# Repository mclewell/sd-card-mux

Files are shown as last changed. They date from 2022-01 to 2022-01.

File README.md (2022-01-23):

# SD-Card-Mux
A tool to automate testing SD-Card images on embedded devices.

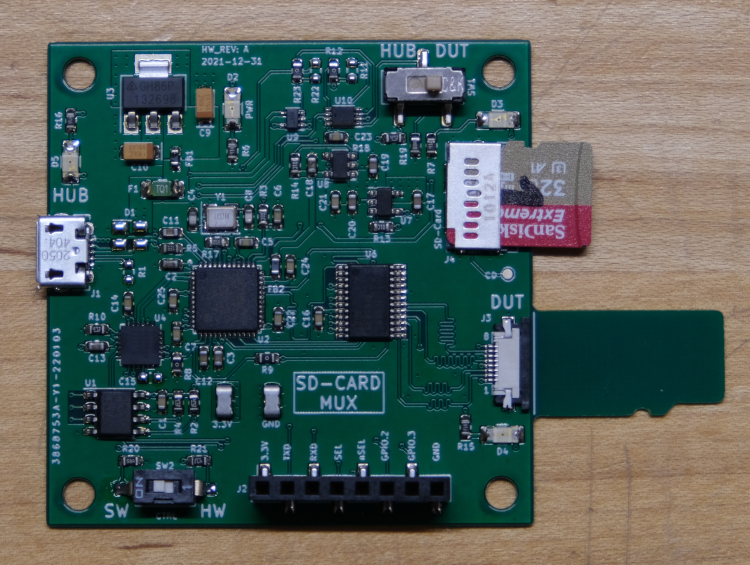
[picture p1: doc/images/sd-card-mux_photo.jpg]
SD-Card-Mux Phot


When developing images for embedded devices, do you often find yourself 
constanly moving the SD-Card between the embedded device and development
computer? Surely there is a way to automate this switching...

The SD-Card Mux sits between the host development computer and an
embedded device, such as a Beaglebone Black, and allows an SD-Card to be 
programatically switched between the two.

SD-Card Mux Block Diagram

The board uses a USB hub (U2640) that contains an SD-Card/MMC interface. A
standard micro-SD Card connects to this interface. One of the other USB ports 
on the hub connects to a USB-UART bridge (CP2102N). This bridge prodives a UART 
interface to the DUT and also controls the switching on the mux (TS3A27518E) 
using the GPIO on the bridge. The GPIO is controlled by the host computer 
using ```libgpiod```. 

Normally, the SD-Card is connected to the host computer. An image that is to be
booted by the DUT is written to the SD-Card. Instead of manually removing the 
card and inserting it into the DUT, a simple script can be added to the 
software development tooling to switch the card from the host computer to the 
embedded DUT.

## Usage
The SD-Card-Mux switching can be either controlled via software or manually
using the switch (```SW1```) on the top of the board.

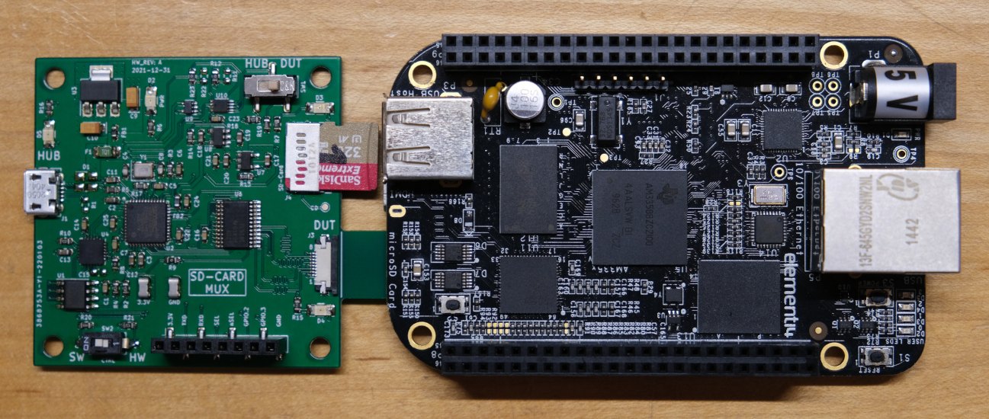
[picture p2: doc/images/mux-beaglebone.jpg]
Mux with Beaglebone Black


### Software Control
Prerequisite: ```libgpiod```

Ubuntu:
```
sudo apt install libgpiod libgpiod-dev
```

Arch: Install from the AUR: 
```
https://aur.archlinux.org/packages/libgpiod/
```

1. Set SW2 (bottom left corner) to 'HW'. (**Note:** Silkscreen labels
on the board are backwards)
2. Insert a micro-sd card into J4.
3. Insert the sd-card-mux into the micro-sd card slot of the development board.
4. Connect a micro-USB cable between the sd-card-mux and development PC.
5. On power-up the sd-card-mux will route the SD card to the DUT, as denoted by the
illuminated LED by the micro-sd protrusion.
6. To switch the SD card to the development PC:
	
	6a. Find the GPIO controller name of the CP210N:
	```
	$ sudo gpiodetect
	gpiochip0 [INT34BB:00] (312 lines)
	gpiochip1 [cp210x] (4 lines)
	```
	6b. The mux control line is on ```GPIO.0```. To switch,
	```
	$ sudo gpioset gpiochip1 0=0
	```
	The LED next to the micro-sd card slot will blink when the SD-Card is
	accessed.

#### UART and Additional GPIO
The SD-Card-Mux also contains a USB-UART serial bridge. Conect the ```TXD```
and ```RXD``` signals in J2 to the UART on the DUT. The bridge should appear
on the development computer as ```/dev/ttyUSB0```.

There are also two additional GPIO from the CP210N broken out into the J2 
header (```GPIO.2```, ```GPIO.3```). These signals can be controlled in the same
fashion as the mux switch function using ```gpioset```. One of these lines can
be connected to the reset of the DUT. Ideally, the DUT should be held in reset
while the SD-card is switched. Once switched over, the reset line can be released
allowing the DUT to boot the new image. 

### Manual Control
1. Set SW2 to the 'SW' position. (**Note:** Silkscreen labels on the board are
backwards)
2. Use SW1 to switch the micro-SD card between the DUT and development 
computer. (**Note:** the silkscreen labels are also backwards here).

# Acknowledgements
- https://wiki.tizen.org/SDWire
- https://github.com/kopasiak/sd-mux

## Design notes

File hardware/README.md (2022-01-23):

# Development Features
Since this was the first hardware spin of the board, some
development features were included.

## Software Switching
The software switching controlled through the CP210N GPIO control
the enable lines of two high-side power switches (```U7```/```U8```).
Only one of these switches should be enabled at a time, therefore the 
complementary output of ```U10``` is used. I had concerns that there
wouldn't be enough 'downtime' during the switch event to allow the 
on-board micro-sd card to fully powerdown before switching. 

The ```U10``` mux can be bypassed by using a GPIO.1 on the CP201N as 
the complementary switching singal. 
- Remove ```R12``` and ```R23```
- Install ```R11``` and ```R22```

During my testing, I have not seen any issues using the single mux
switch control line and mux complementary out.

## DUT Connection via FFC
A Flex-Flex Cable (FFC) header (```J3```) is provided to allow connections
to the DUT via a flex cable. The other end of the cable is connected to a
micro-sd breakout board, which is provided in this repo 
[here](microsd-breakout).

# Known Issues
- Silkscreen labels on ```S1``` and ```SW2``` are reversed.
- On-board micro-sd card in ```J4``` protrudes over the board edge
and may interfer with the DUT.
- The USB ESD protection (```D1```) caused the USB hub to fail to enumerate
at high-speed modes, full-speed works correctly. Removing ```D1``` solves
this issue.

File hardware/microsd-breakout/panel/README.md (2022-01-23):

The micro-sd breakout board can be panelized using 
[kikit](https://github.com/yaqwsx/KiKit). The panel parameters
are defined in ```panelize.json``` 

Run ```mk-panel.sh``` to generate a 2x5 panel of micro-sd breakout
board.

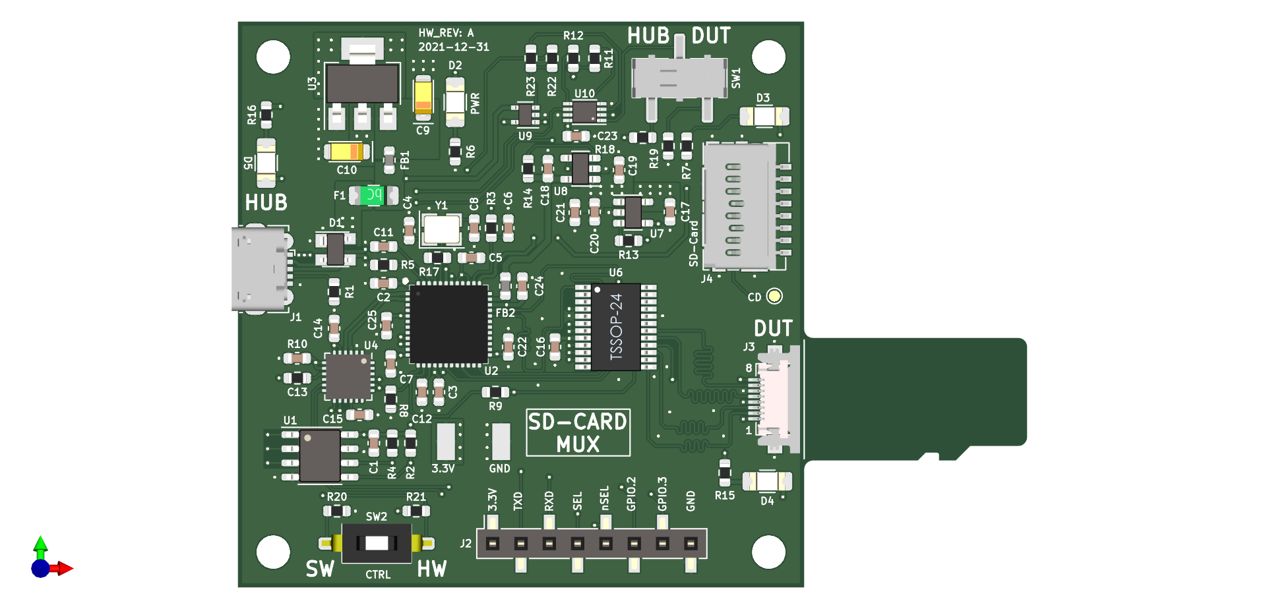
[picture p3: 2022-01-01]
doc/images/sd-card-mux.png

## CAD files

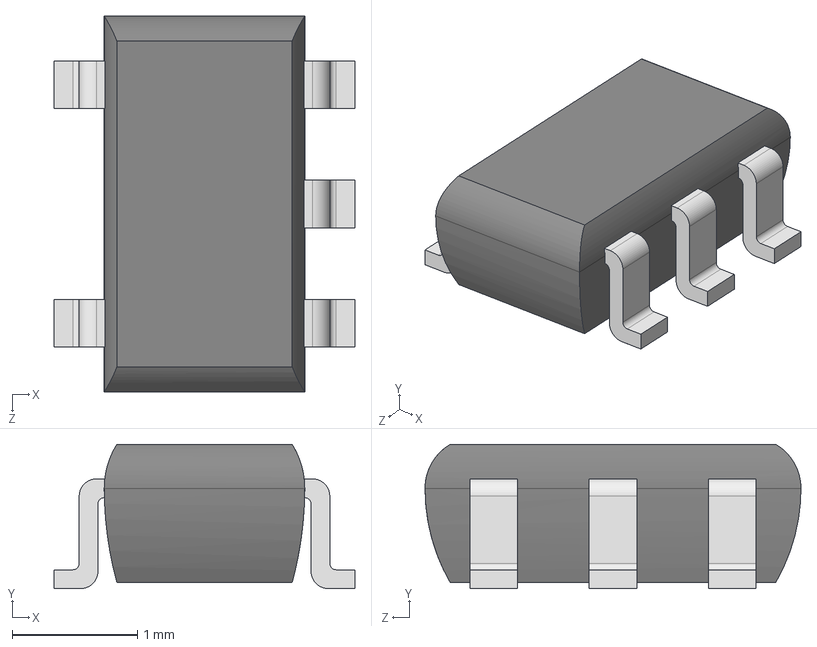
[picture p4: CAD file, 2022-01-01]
hardware/main/models/sot25.step
2.40 x 1.15 x 3.00 mm

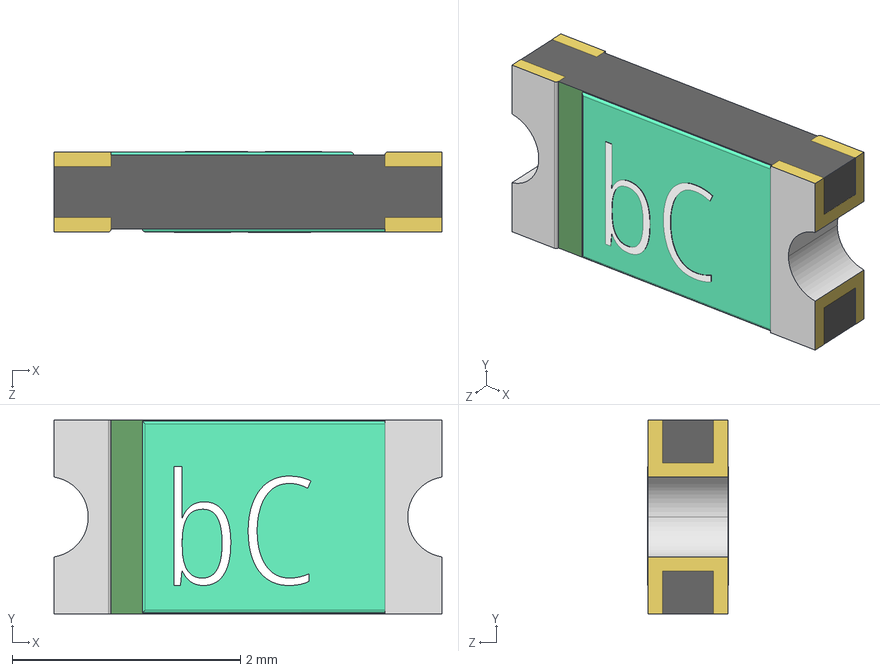
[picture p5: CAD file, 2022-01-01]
hardware/main/models/0ZCJ0005FF2E.step
3.40 x 1.70 x 0.708 mm

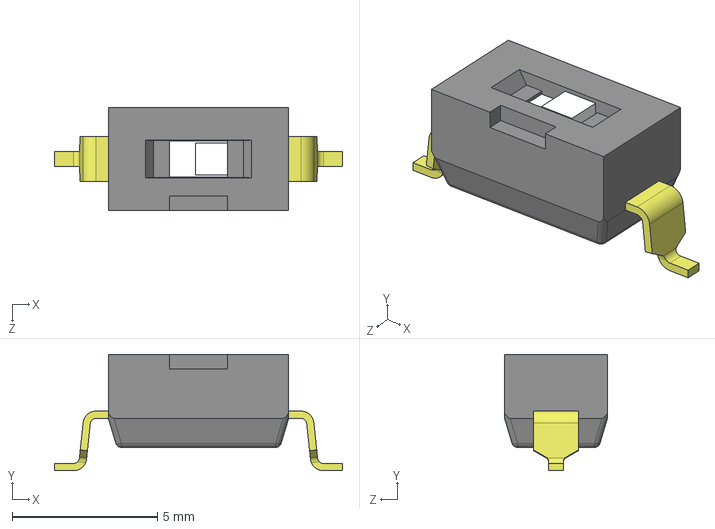
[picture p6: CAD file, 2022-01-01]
hardware/main/models/CUI_DEVICES_DS04-254-2-01BK-SMT.step
9.90 x 4.00 x 3.54 mm

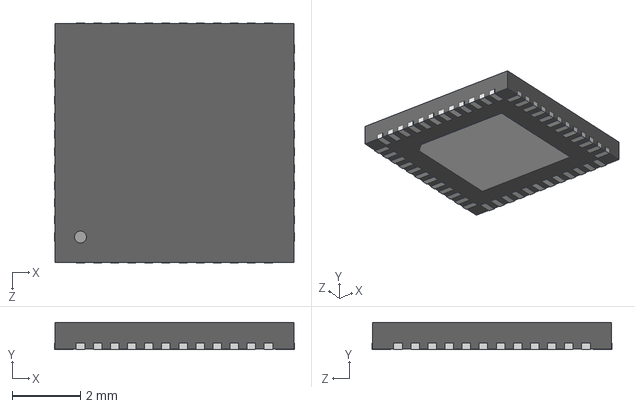
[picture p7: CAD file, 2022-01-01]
hardware/main/models/QFN48_7x7.step
7.02 x 0.8 x 7.02 mm

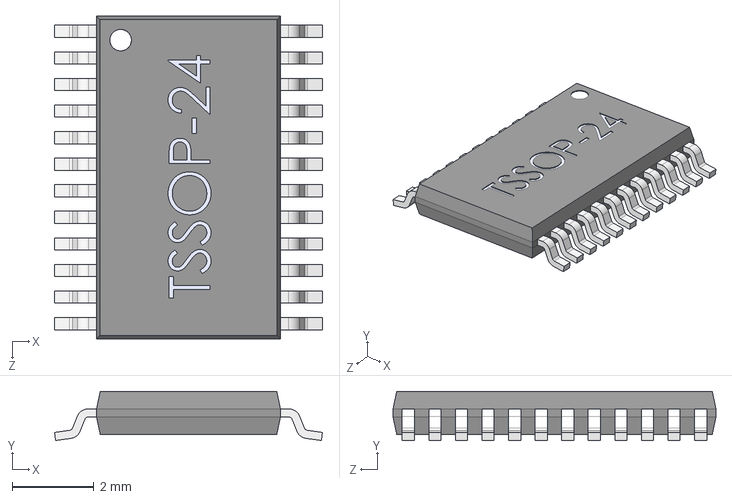
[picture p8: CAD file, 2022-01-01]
hardware/main/models/TSSOP24.step
6.56 x 1.20 x 7.90 mm

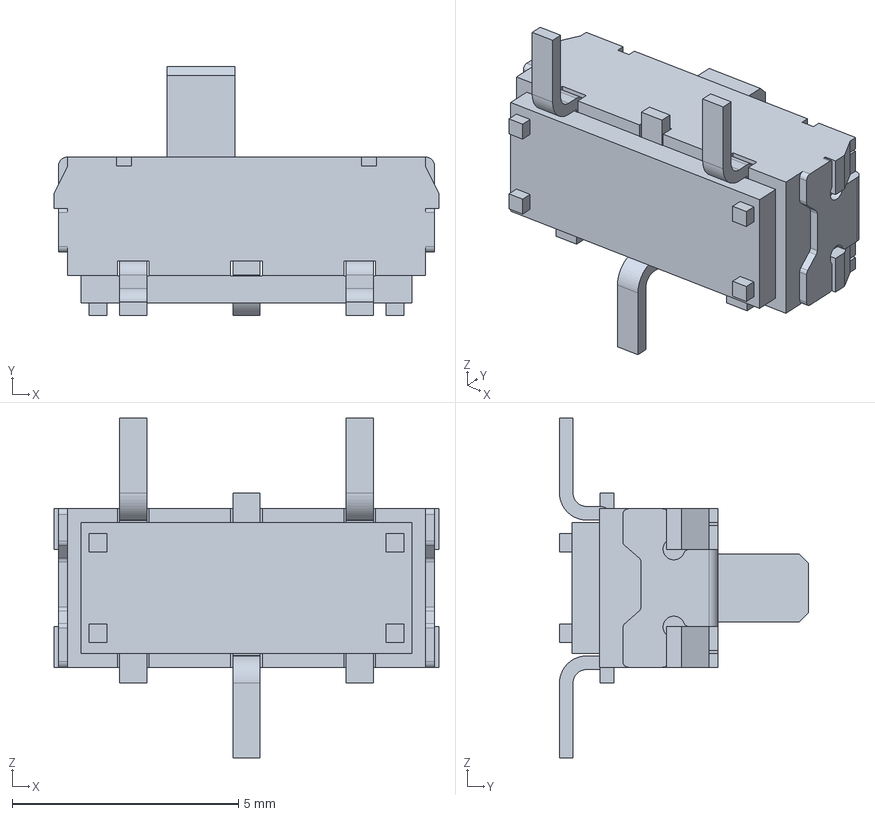
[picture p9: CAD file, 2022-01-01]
hardware/main/models/JS102011SCQN.stp
8.50 x 5.50 x 7.50 mm

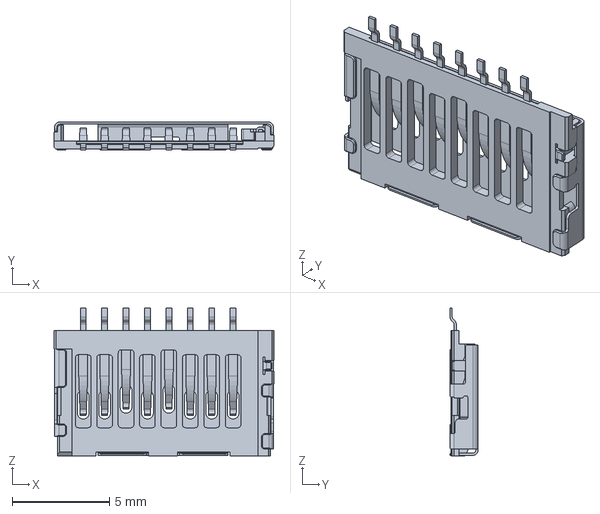
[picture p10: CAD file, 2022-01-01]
hardware/main/models/1051620001.stp
11.3 x 1.45 x 7.60 mm

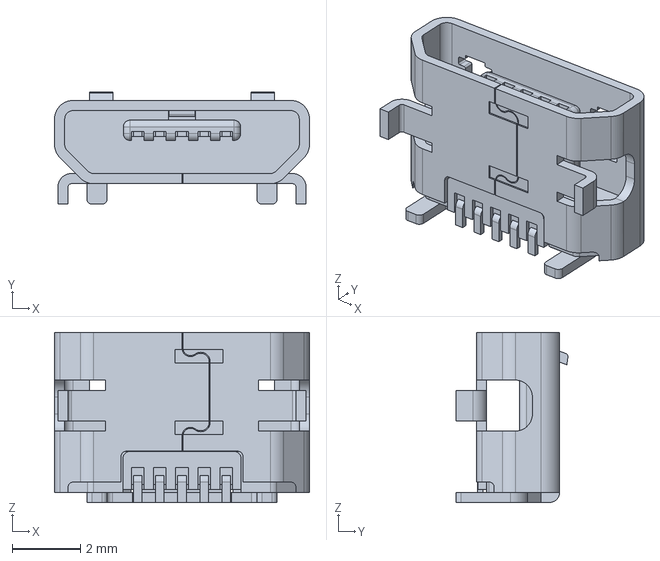
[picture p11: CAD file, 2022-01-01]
hardware/main/models/1050171001.stp
7.50 x 3.30 x 5.00 mm

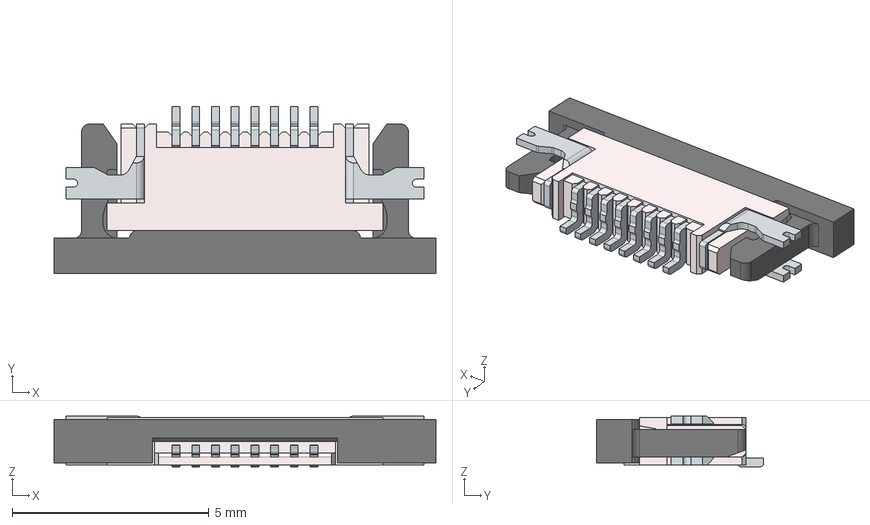
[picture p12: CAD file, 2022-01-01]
hardware/main/models/687108183722.stp
9.70 x 4.25 x 1.29 mm
68x108183x22
68X1XX183X22_Pin_Bottom x 8
68x108183x22_Actuator
68X1XX183X22_Solder_Pad
68X1xx183x22_Solder_Pad2

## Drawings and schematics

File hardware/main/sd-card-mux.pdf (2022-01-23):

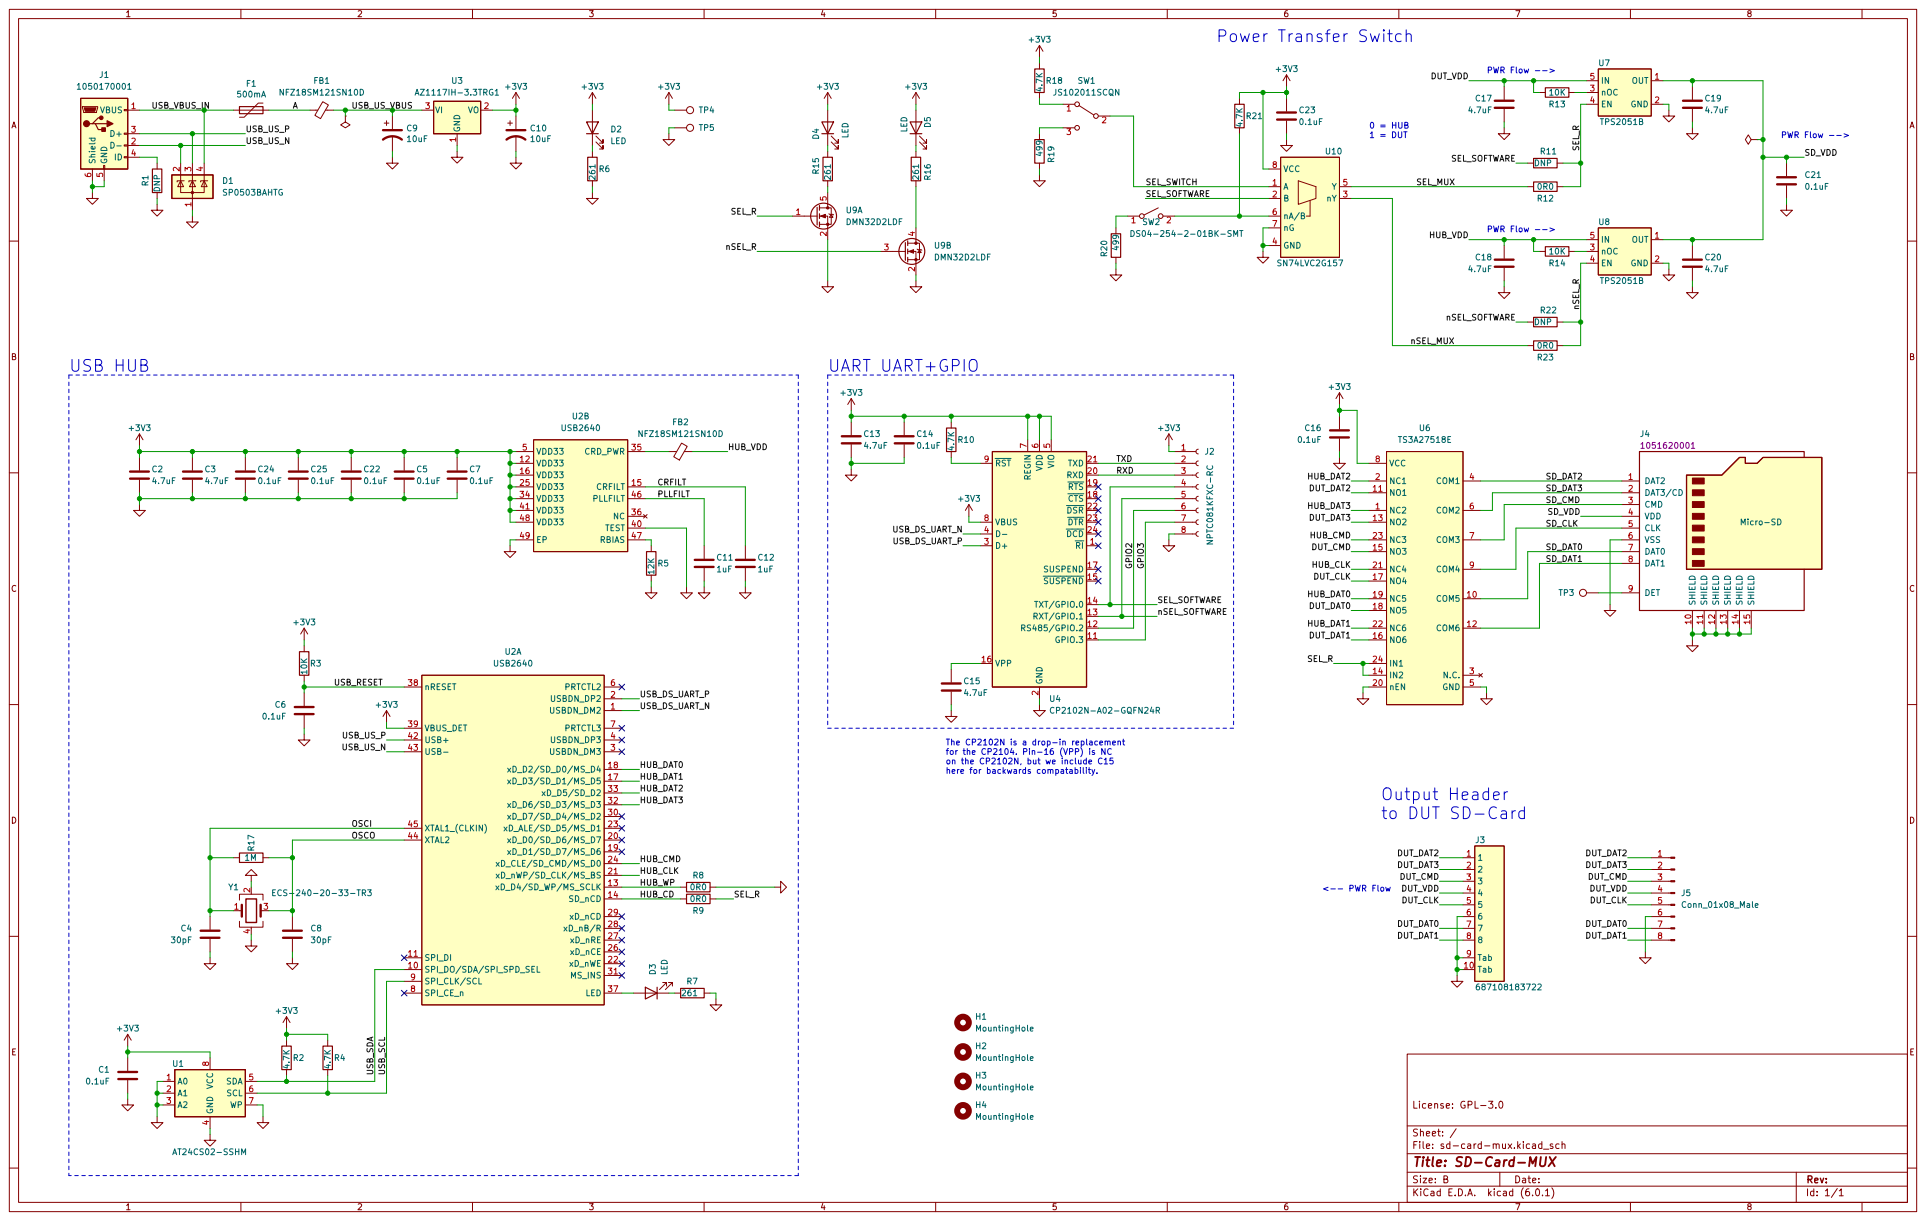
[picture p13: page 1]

PWR Flow --> UART UART+GPIO

2 RXD 20 TXD 21 ~{DSR}22 ~{DTR}23 ~{DCD}24 D+ 3 D- 4 VIO

The CP2102N is a drop-in replacement
for the CP2104. Pin-16 (VPP) is NC
on the CP2102N, but we include C15
here for backwards compatability.

<-- PWR Flow Output Header

to DUT SD-Card

4 SDA 5 SCL 6 WP 7 VCC

File: sd-card-mux.kicad_sch Sheet: / License: GPL-3.0

Id: 1/1 Title: SD-Card-MUX

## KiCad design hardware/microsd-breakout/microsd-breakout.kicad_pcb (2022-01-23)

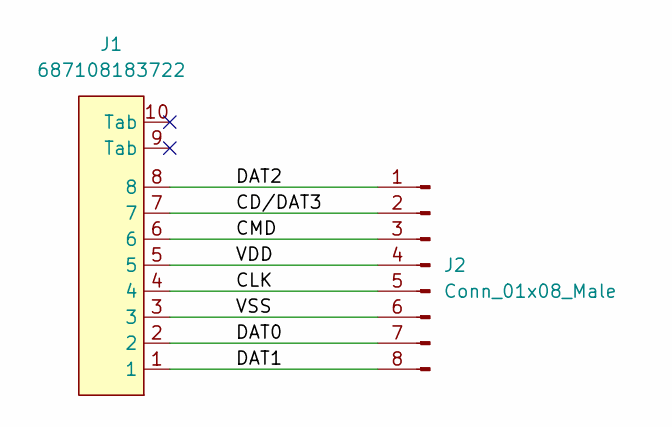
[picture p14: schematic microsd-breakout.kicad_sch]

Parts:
J1: 687108183722; Wurth_FPC_687108183722; PartNumber 687108183722
J2: Conn_01x08_Male; micro-sd-contacts

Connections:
/CD/DAT3: J1.7, J2.2
/CLK: J1.4, J2.5
/CMD: J1.6, J2.3
/DAT0: J1.2, J2.7
/DAT1: J1.1, J2.8
/DAT2: J1.8, J2.1
/VDD: J1.5, J2.4
/VSS: J1.3, J2.6

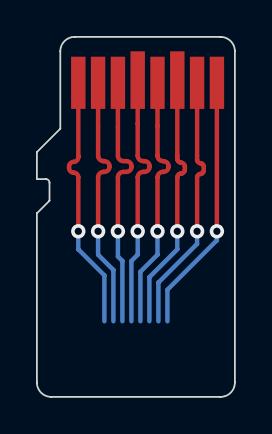
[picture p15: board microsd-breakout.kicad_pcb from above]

Board: 2 copper layers, 11.0 x 20.0 mm, 3 parts (1 on the bottom side), 8 nets.

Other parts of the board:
REF1: Tab

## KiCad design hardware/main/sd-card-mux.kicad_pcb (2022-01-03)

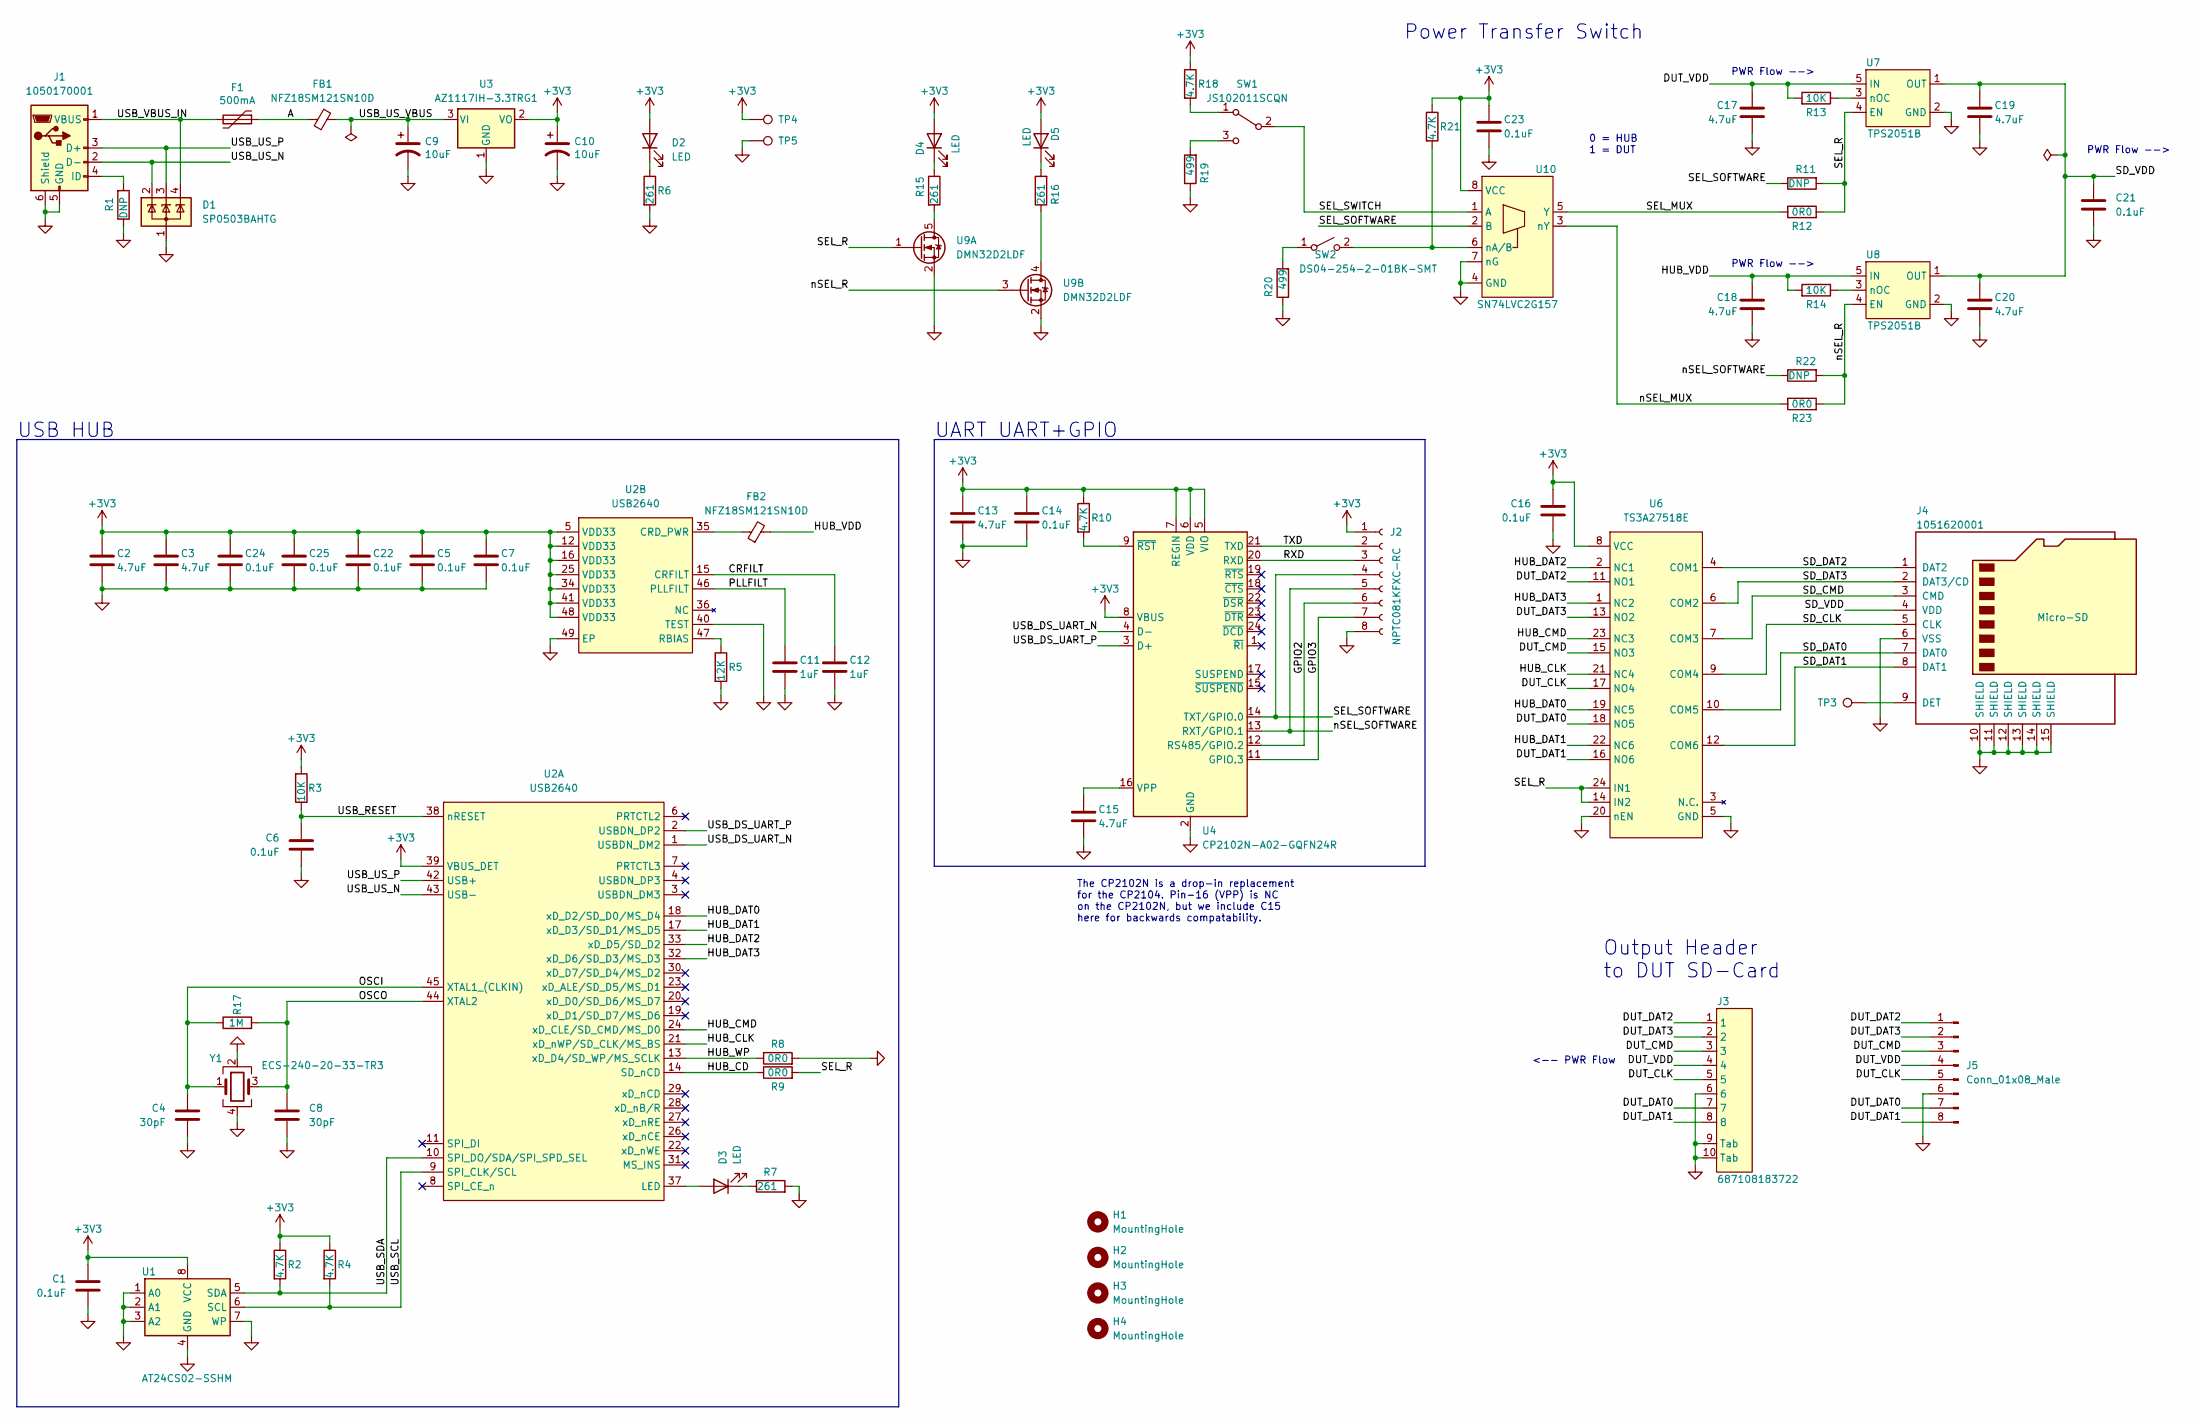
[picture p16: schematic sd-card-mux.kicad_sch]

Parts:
C1, C5, C6, C7, C14, C16, C21, C22, C23, C24, C25: 0.1uF; C_0603_1608Metric
C2, C3, C13, C15, C17, C18, C19, C20: 4.7uF; C_0603_1608Metric
C4, C8: 30pF; C_0603_1608Metric
C9, C10: 10uF; CP_EIA-3216-18_Kemet-A; PartNumber TAJA106K016SNJ
C11, C12: 1uF; C_0603_1608Metric
D1: SP0503BAHTG; SOT-143; PartNumber SP0503BAHTG
D2, D3, D4, D5: LED; LED_1206_3216Metric_Castellated
F1: 500mA; Fuse_1206_3216Metric_Castellated; PartNumber PTS120615V050
FB1, FB2: ‎NFZ18SM121SN10D‎; L_0603_1608Metric; PartNumber ‎NFZ18SM121SN10D‎
H1, H2, H3, H4: MountingHole; MountingHole_3.2mm_M3
J1: 1050170001; USB_Micro-B_Molex-105017-0001; PartNumber 1050170001
J2: NPTC081KFXC-RC; PinSocket_1x08_P2.54mm_Vertical_SMD_Pin1Right; PartNumber NPTC081KFXC-RC
J3: 687108183722; Wurth_FPC_687108183722; PartNumber 687108183722
J4: Micro-SD; micro-sd; PartNumber 1051620001
J5: Conn_01x08_Male; micro-sd-contacts
R1, R11, R22: DNP; R_0603_1608Metric
R2, R4, R10, R18, R21: 4.7K; R_0603_1608Metric
R3, R13, R14: 10K; R_0603_1608Metric
R5: 12K; R_0603_1608Metric
R6, R7, R15, R16: 261; R_0603_1608Metric
R8, R9, R12, R23: 0R0; R_0603_1608Metric
R17: 1M; R_0603_1608Metric
R19, R20: 499; R_0603_1608Metric
SW1: JS102011SCQN; CK_Switch_JS102011SCQN; PartNumber JS102011SCQN
SW2: DS04-254-2-01BK-SMT; CUI_DEVICES_DS04-254-2-01BK-SMT; PartNumber DS04-254-2-01BK-SMT
TP3: TestPoint; TestPoint_Pad_D1.0mm
TP4, TP5: TestPoint; test_point_RCSCTE; PartNumber RCSCTE
U1: AT24CS02-SSHM; SOIC-8_3.9x4.9mm_P1.27mm; PartNumber AT24CS02-SSHM-B
U2: USB2640; VQFN-48; PartNumber USB2640-HZH-02
U3: AZ1117IH-3.3TRG1; SOT-223-3_TabPin2; PartNumber AZ1117IH-3.3TRG1
U4: CP2102N-A02-GQFN24R; QFN-24-1EP_4x4mm_P0.5mm_EP2.6x2.6mm; PartNumber CP2102N-A02-GQFN24R
U6: TS3A27518E; TI_PW; PartNumber TS3A27518EPWR
U7, U8: TPS2051B; SOT-23-5; PartNumber TPS2051BDBVR
U9: DMN32D2LDF; SOT-353_SC-70-5; PartNumber DMN32D2LDF-7
U10: SN74LVC2G157; VSSOP-8_2.3x2mm_P0.5mm; PartNumber SN74LVC2G157DCU3
Y1: ECS-240-20-33-TR3; Crystal_SMD_Abracon_ABM8G-4Pin_3.2x2.5mm; PartNumber ECS-240-20-33-TR3

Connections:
+3V3: C1.2, C2.1, C3.1, C5.1, C7.1, C10.1, C13.1, C14.1, C16.2, C22.1, C23.1, C24.1, C25.1, D2.2 (A), D4.2 (A), D5.2 (A), J2.1, R2.1, R3.2, R4.1, R10.1, R18.1, R21.1, TP4.1, U1.8 (VCC), U2.5 (VDD33), U2.12 (VDD33), U2.16 (VDD33), U2.25 (VDD33), U2.34 (VDD33), U2.39 (VBUS_DET), U2.41 (VDD33), U2.48 (VDD33), U3.2 (VO), U4.5 (VIO), U4.6 (VDD), U4.7 (REGIN), U4.8 (VBUS), U6.8 (VCC), U10.8 (VCC)
/A: F1.1, FB1.1
/CRFILT: C12.1, U2.15 (CRFILT)
/DUT_CLK: J3.5, J5.5, U6.17 (NO4)
/DUT_CMD: J3.3, J5.3, U6.15 (NO3)
/DUT_DAT0: J3.7, J5.7, U6.18 (NO5)
/DUT_DAT1: J3.8, J5.8, U6.16 (NO6)
/DUT_DAT2: J3.1, J5.1, U6.11 (NO1)
/DUT_DAT3: J3.2, J5.2, U6.13 (NO2)
/DUT_VDD: C17.1, J3.4, J5.4, R13.2, U7.5 (IN)
/GPIO2: J2.6, U4.12 (RS485/GPIO.2)
/GPIO3: J2.7, U4.11 (GPIO.3)
/HUB_CD: R9.1, U2.14 (SD_nCD)
/HUB_CLK: U2.21 (xD_nWP/SD_CLK/MS_BS), U6.21 (NC4)
/HUB_CMD: U2.24 (xD_CLE/SD_CMD/MS_D0), U6.23 (NC3)
/HUB_DAT0: U2.18 (xD_D2/SD_D0/MS_D4), U6.19 (NC5)
/HUB_DAT1: U2.17 (xD_D3/SD_D1/MS_D5), U6.22 (NC6)
/HUB_DAT2: U2.33 (xD_D5/SD_D2), U6.2 (NC1)
/HUB_DAT3: U2.32 (xD_D6/SD_D3/MS_D3), U6.1 (NC2)
/HUB_VDD: C18.1, FB2.2, R14.2, U8.5 (IN)
/HUB_WP: R8.1, U2.13 (xD_D4/SD_WP/MS_SCLK)
/OSCI: C4.2, R17.1, U2.45 (XTAL1_(CLKIN)), Y1.1
/OSCO: C8.1, R17.2, U2.44 (XTAL2), Y1.3
/PLLFILT: C11.1, U2.46 (PLLFILT)
/RXD: J2.3, U4.20 (RXD)
/SD_CLK: J4.5 (CLK), U6.9 (COM4)
/SD_CMD: J4.3 (CMD), U6.7 (COM3)
/SD_DAT0: J4.7 (DAT0), U6.10 (COM5)
/SD_DAT1: J4.8 (DAT1), U6.12 (COM6)
/SD_DAT2: J4.1 (DAT2), U6.4 (COM1)
/SD_DAT3: J4.2 (DAT3/CD), U6.6 (COM2)
/SD_VDD: C19.1, C20.1, C21.2, J4.4 (VDD), U7.1 (OUT), U8.1 (OUT)
/SEL_MUX: R12.1, U10.5 (Y)
/SEL_R: R9.2, R11.2, R12.2, U6.14 (IN2), U6.24 (IN1), U7.4 (EN), U9.1 (G1)
/SEL_SOFTWARE: J2.4, R11.1, U4.14 (TXT/GPIO.0), U10.2 (B)
/SEL_SWITCH: SW1.2 (B), U10.1 (A)
/TXD: J2.2, U4.21 (TXD)
/USB_DS_UART_N: U2.1 (USBDN_DM2), U4.4 (D-)
/USB_DS_UART_P: U2.2 (USBDN_DP2), U4.3 (D+)
/USB_RESET: C6.2, R3.1, U2.38 (nRESET)
/USB_SCL: R4.2, U1.6 (SCL), U2.9 (SPI_CLK/SCL)
/USB_SDA: R2.2, U1.5 (SDA), U2.10 (SPI_DO/SDA/SPI_SPD_SEL)
/USB_US_N: D1.2 (K), J1.2 (D-), U2.43 (USB-)
/USB_US_P: D1.3 (K), J1.3 (D+), U2.42 (USB+)
/USB_US_VBUS: C9.1, FB1.2, U3.3 (VI)
/USB_VBUS_IN: D1.4 (K), F1.2, J1.1 (VBUS)
/nSEL_MUX: R23.1, U10.3 (nY)
/nSEL_R: R22.2, R23.2, U8.4 (EN), U9.3 (G2)
/nSEL_SOFTWARE: J2.5, R22.1, U4.13 (RXT/GPIO.1)
GND: C1.1, C2.2, C3.2, C4.1, C5.2, C6.1, C7.2, C8.2, C9.2, C10.2, C11.2, C12.2, C13.2, C14.2, C15.2, C16.1, C17.2, C18.2, C19.2, C20.2, C21.1, C22.2, C23.2, C24.2, C25.2, D1.1 (A), J1.5 (GND), J1.6 (Shield), J2.8, J3.6, J3.9 (Tab), J3.10 (Tab), J4.6 (VSS), J4.10 (SHIELD), J4.11 (SHIELD), J4.12 (SHIELD), J4.13 (SHIELD), J4.14 (SHIELD), J4.15 (SHIELD), J5.6, R1.1, R5.2, R6.2, R7.2, R8.2, R19.1, R20.1, TP5.1, U1.1 (A0), U1.2 (A1), U1.3 (A2), U1.4 (GND), U1.7 (WP), U2.40 (TEST), U2.49 (EP), U3.1 (GND), U4.2 (GND), U4.25 (GND), U6.5 (GND), U6.20 (nEN), U7.2 (GND), U8.2 (GND), U9.2 (S), U10.4 (GND), U10.7 (nG), Y1.2, Y1.4
unnamed: C15.1, U4.16 (VPP)
unnamed: D2.1 (K), R6.1
unnamed: D3.1 (K), R7.1
unnamed: D3.2 (A), U2.37 (LED)
unnamed: D4.1 (K), R15.1
unnamed: D5.1 (K), R16.2
unnamed: FB2.1, U2.35 (CRD_PWR)
unnamed: J1.4 (ID), R1.2
unnamed: J4.9 (DET), TP3.1
unnamed: R5.1, U2.47 (RBIAS)
unnamed: R10.2, U4.9 (~RST)
unnamed: R13.1, U7.3 (nOC)
unnamed: R14.1, U8.3 (nOC)
unnamed: R15.2, U9.5 (D1)
unnamed: R16.1, U9.4 (D2)
unnamed: R18.2, SW1.1 (A)
unnamed: R19.2, SW1.3 (C)
unnamed: R20.2, SW2.1 (A)
unnamed: R21.2, SW2.2 (B), U10.6 (nA/B)

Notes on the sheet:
The CP2102N is a drop-in replacement for the CP2104. Pin-16 (VPP) is NC on the CP2102N, but we include C15 here for backwards compatability.
Power Transfer Switch
0 = HUB 1 = DUT
<-- PWR Flow
PWR Flow -->
Output Header to DUT SD-Card
USB HUB
UART UART+GPIO

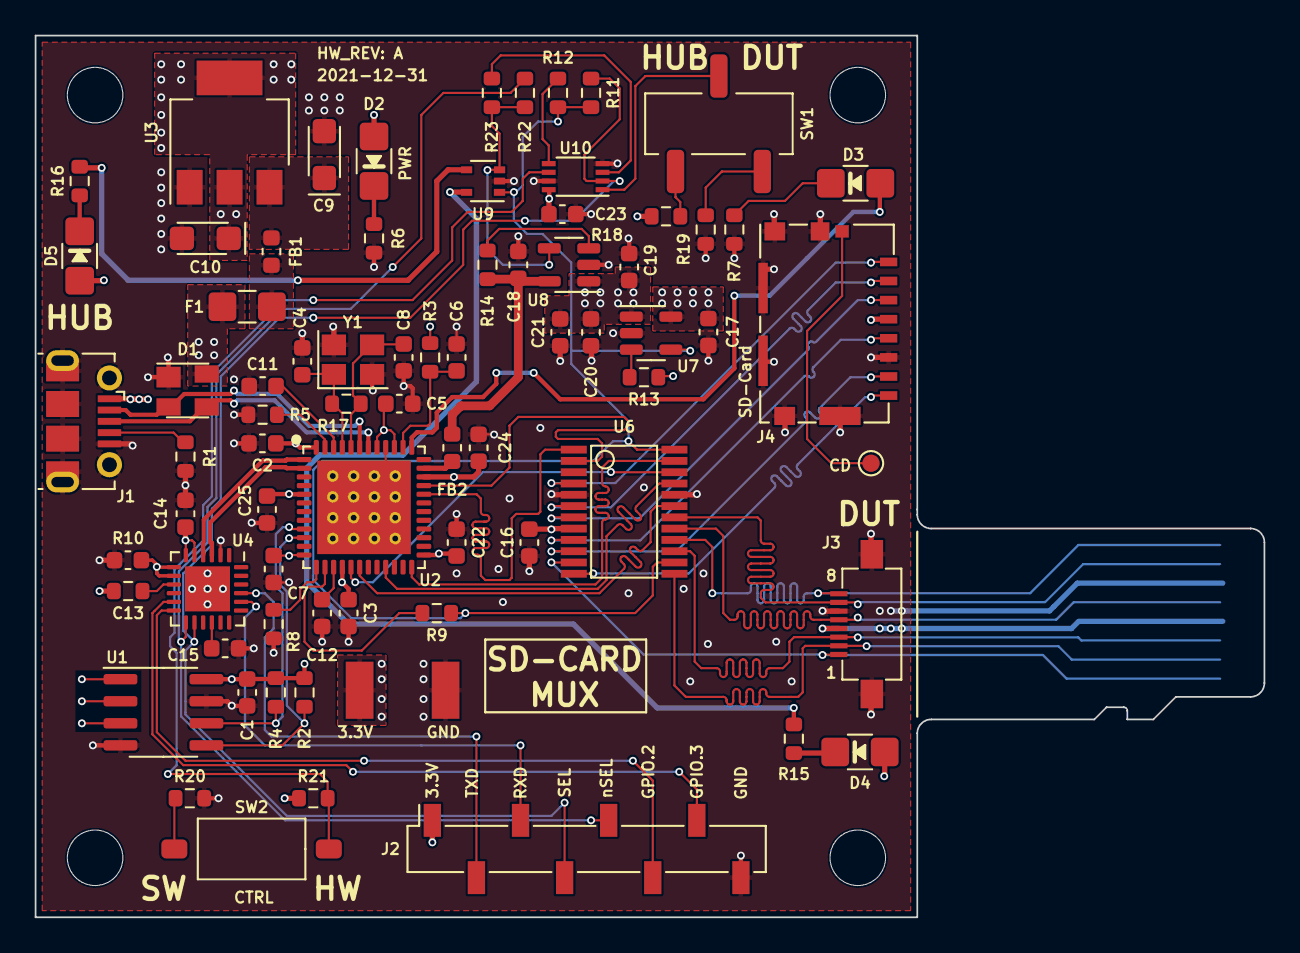
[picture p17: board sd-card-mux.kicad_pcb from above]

Board: 4 copper layers, 70.8 x 50.8 mm, 80 parts (1 on the bottom side), 69 nets.

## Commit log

2022-01-03 Updated PCB gerber generation settings and add gerbers.
    [sd-card-mux-B_Cu.gbl, sd-card-mux-B_Mask.gbs, sd-card-mux-B_Paste.gbp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]
2022-01-13 Added breakout board for micro-sd
    [microsd-breakout.kicad_pcb, microsd-breakout.kicad_sch]
2022-01-23 Added breakout board and documentation.
    [microsd-breakout.kicad_pcb, output.kicad_pcb, sd-card-mux.kicad_sch]
